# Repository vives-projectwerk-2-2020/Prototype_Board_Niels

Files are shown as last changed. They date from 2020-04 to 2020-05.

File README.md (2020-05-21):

# Prototype board with sensors

## Description

In this readme you can find all information about the prototype board with sensors. I made first a test board this board cannot be placed inside the box. This board works perfect with all sensors. The second board i made is made to put inside the box, i also implemented extra pins for the other boards. I also added a extra part to get the SDS011 sensor in sleep mode i will explain this in the info below.

## The nucleo

The central part of my board is the nucleo-L432KC. The STM32 Nucleo-32 board provides an affordable and flexible way for users to try out new concepts and build prototypes with the STM32 microcontroller, choosing from the various combinations of performance, power consumption and features. In the picture below you can see how the nucleo looks like and how the pins are devided. If i talk about pins in the info beneeth you can look on this picture where you can find the pins.

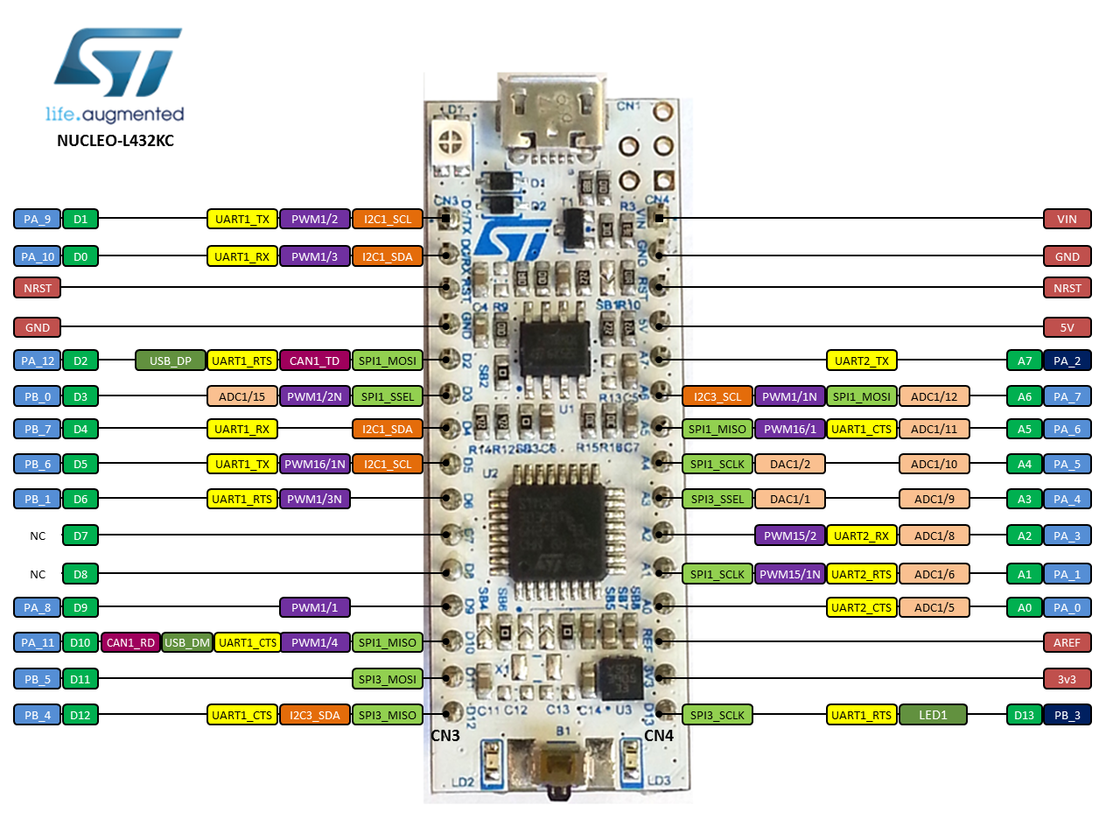
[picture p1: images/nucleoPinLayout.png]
nucleo pin layout


## Shematic of the old board

In this shematic you see in the center of the shematic 2 big blocks the top one is the left side of the nucleo-L432KC. The block below is the right side of the nucleo-L432KC. On the right side from the second nucleo-L432KC block you can see 2 pins they are called JP2 and JP3. These pins were provided for the solar panel board, JP2 is connected with the Vin from the nucleo and JP3 is just the ground. There is also a reset button connected to NRST on the nucleo.

Right below the pins JP2 and JP3 you can see one big connector, this is the connector for connecting the LoRaWAN-antenna board. Pins 1, 8, 9 are connected to the ground, pin 12 is connected with the 3V3 and a capacitor with a value of 100 nF.
Pins 7, 10, 11, 15 are not connected, pin 2 is connected to pin D12 on the nucleo. Pin 3 is connected with D11 on the nucleo, pin 4 is connected with D13 on the nucleo, pin 5 is connected with D0 on the nucleo. Pin 6 is connected with a resistor with a value of 4k7 ohm, this pin is also connected with D1 on the nucleo. Pin 13 is connected with D2 on the nucleo, pin 14 is connected with D3 on the nucleo.

Left from the top block from the nulceo you can see a connector that is called SDS011. This connector has pins so that you connect the SDS011 sensor on it. You can see that pin 1 is not connected this is because the connector from the SDS011 has 5 pins and one is not connected. Pin 2 is connected to 3v3 but this has been changed in the newer shematic because the sensor has to work on 5V, pin 3 is connected to the ground. Pin 4 is connected to D1 on the nucleo and Pin 5 is connected to D0 on the nucleo.

Right from the top block from the nulceo you can see a connector that is called BME280. This connector has female pins so you can put the BME280 sensor on it. Pin 2 is not connected, Pin 1 and 7 are connected to 3V3 and pin 3 and 5 are connected to the ground. Pin 4 is connected to D5 on the nucleo and pin 6 is connected to D4 on the nucleo.

On top of the shematic you can see a big block this is the EEPROM. Pin 2 is connected to the ground and pin 4 is connected to the VCC. Pin 5 is not connected, pin 1 is connected to a resistor with a value of 2k2 ohm to protect the SCL line and is connected tot the D5 on the nucleo. Pin 3 is connected to a resistor with a value of 2k2 ohm to protect the SDA line and is connected with D4 on the nucleo.

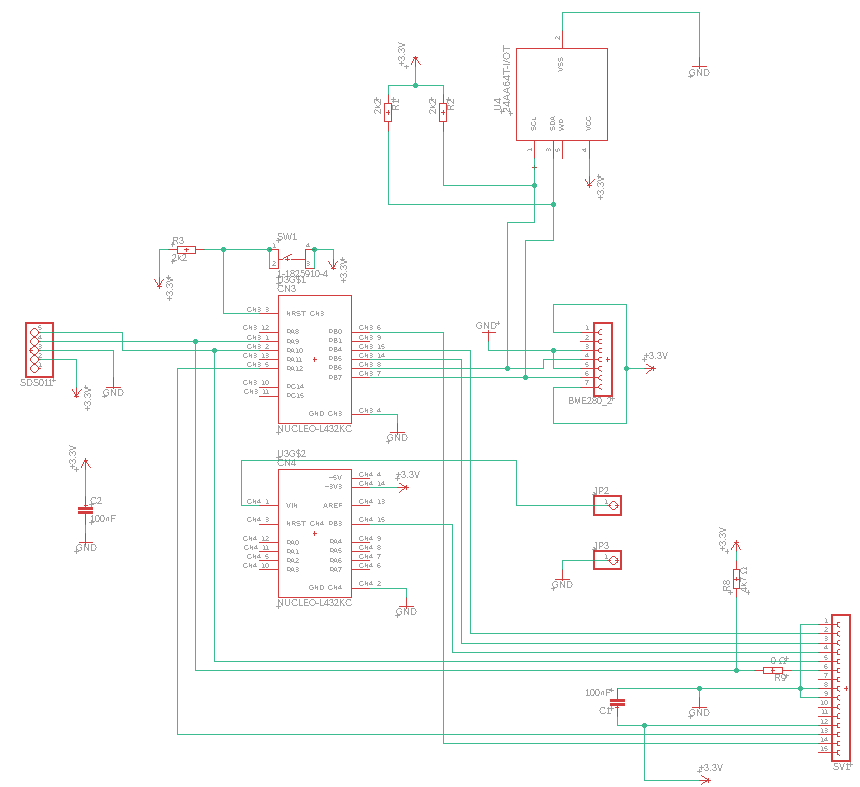
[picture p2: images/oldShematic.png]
old shematic


## Block diagram old board

Here can you see the block diagram of the old board. This block diagram is a quick summary of what is on my old board.

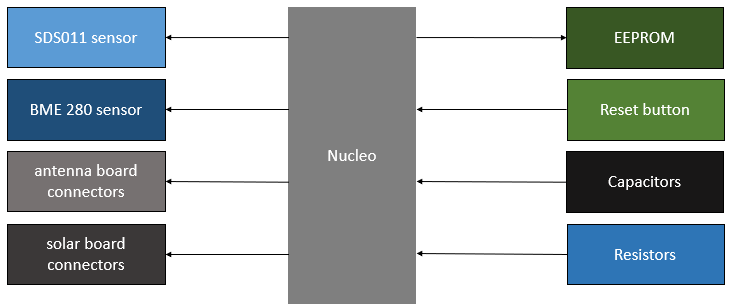
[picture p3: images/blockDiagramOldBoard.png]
old block diagram


## Board shematic of the old board

On the top of the board you can see 4 holes this is the VCC of the SDS011 sensor. These holes are were provided so you could erase the line and add more voltage to it from the solar pannel board. These holes were removed on the newest board.

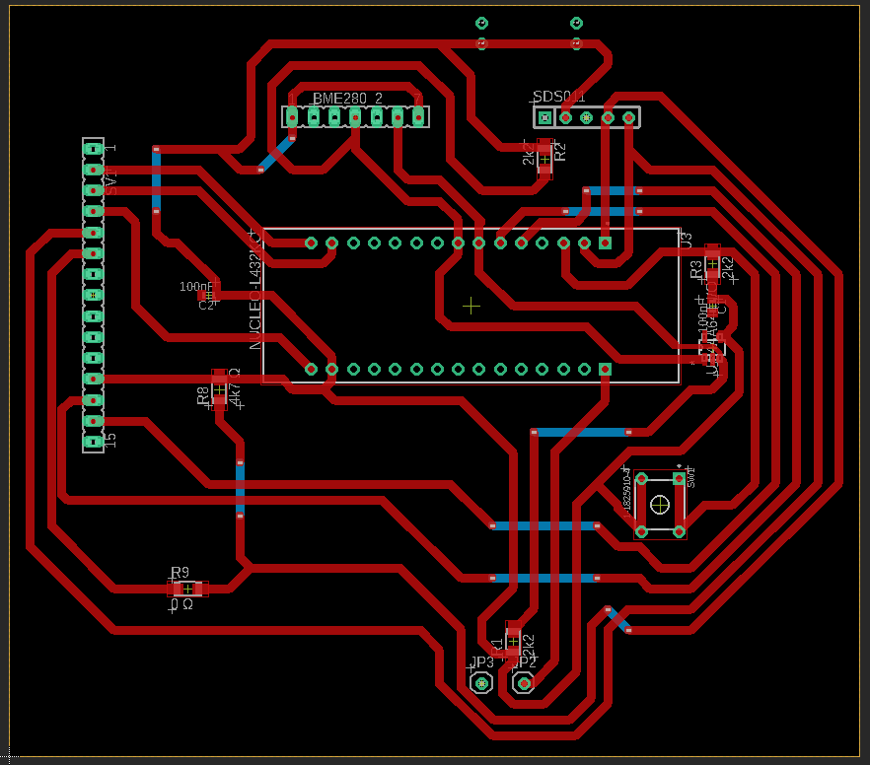
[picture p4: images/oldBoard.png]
old board


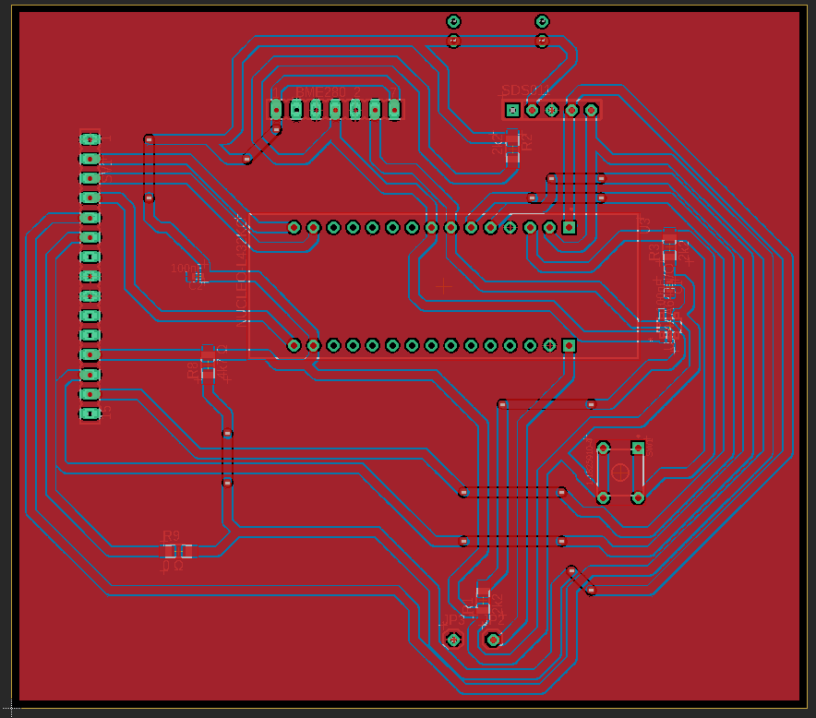
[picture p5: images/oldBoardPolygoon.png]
old board polygoon


## The print when nothing was soldered

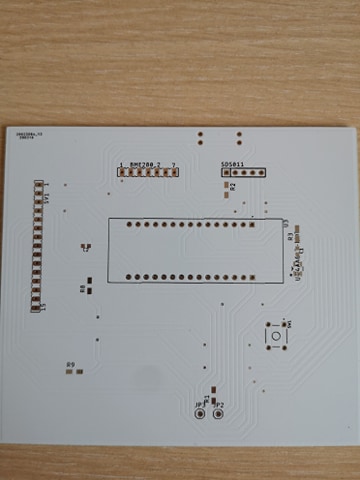
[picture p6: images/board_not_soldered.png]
print not soldered


## The print when everything is soldered

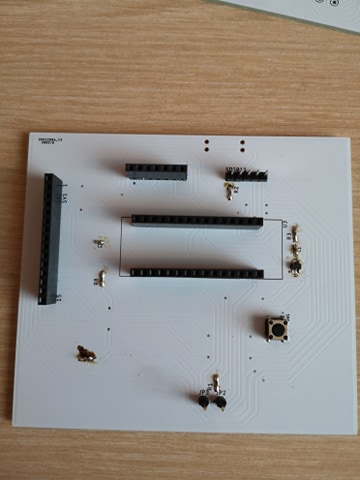
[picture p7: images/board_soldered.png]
print soldered


## Testing the SDS011 sensor

1. Setup of the sensor.

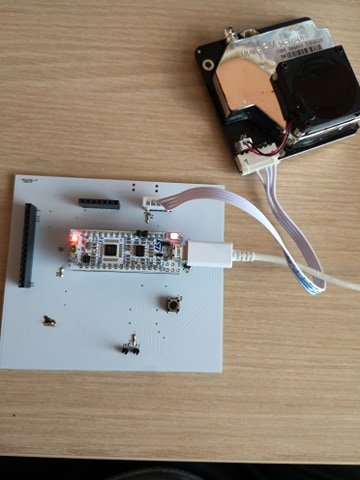
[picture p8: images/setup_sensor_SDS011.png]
setup SDS011
   

2. Reading the values in putty.

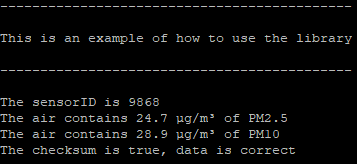
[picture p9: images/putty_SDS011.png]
putty SDS011
   

3. Extra information.
    * The pins are connected on D0 and D1.

## Testing the EEPROM driver

1. Setup of the sensor.

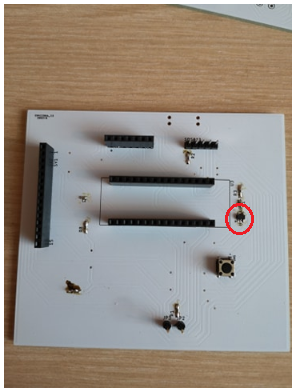
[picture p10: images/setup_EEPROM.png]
setup EEPROM
   

2. Reading out an array in putty.

   putty EEPROM

3. Extra information.
    * While testing i connected the pins to D4 and D5.

## Testing the BME280 sensor

I could not test this sensor because i don't have that sensor at home. I tested it with the fake values from Ladzlo and something was wrong with compiling. But other people tried this sensor and connected it just like how i connected it in my shematic so normally it would work perfectly.

1. Setup of the sensor.

   Connect the sensor in the pins in the red circle shown in the picture below.

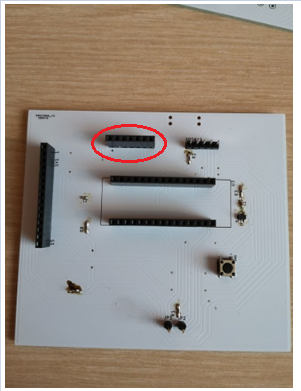
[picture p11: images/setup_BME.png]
setup BME
   

2. Extra information.
    * I connected the BME to pins D4 and D5 on the nucleo.

## Testing antenna PCB board

This test has been executed by Laura this pcb works perfectly together with my board all the info about the tests can you find in the github repository from the antenna board.

1. Setup of the boards.

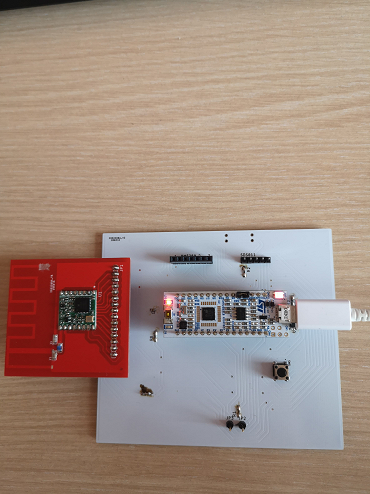
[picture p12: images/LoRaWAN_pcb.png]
setup LoRaWan
   

2. Extra information.
    * You can find extra information in the link below.
    * [Link testing LoRaWAN-antenna](https://github.com/vives-projectwerk-2-2020/LoRaWAN-antenna)

## Shematic of the new board

The difference between the old and the new board is that i added extra pins for the battery pcb and also pins for an extra board so that the voltage can go from 3V3 to 5V so that the SDS011 sensor can work well. I also added sleep mode for the SDS011.

Left from the lowest nucleo shematic i added added 3 extra connectors. SV3 is provided so that the solar board can be connected to my board. SV2 are connectors to add the extra print that converts te voltage 3V3 to 5V, we have to do that so that the SDS011 can function well.

Below the SV2 connector there are 2 pins these pins are provided to connect the wires from the batteries to my pcb. In the board you can also see a lot of holes. These holes are provided to connect the pcb with the box, the 2 holes in the center are provided for the batteries you can connect these under the PCB or above.

In the top left of the shematic you can see i added there also extra components. These components are provided so that the SDS011 can go in sleep mode. I connected this to pin D2 on the nucleo, the info about the shematic can you find in the topic "Adding components to the old board so that the SDS011 sensor can go in sleep mode" this will be discussed below.

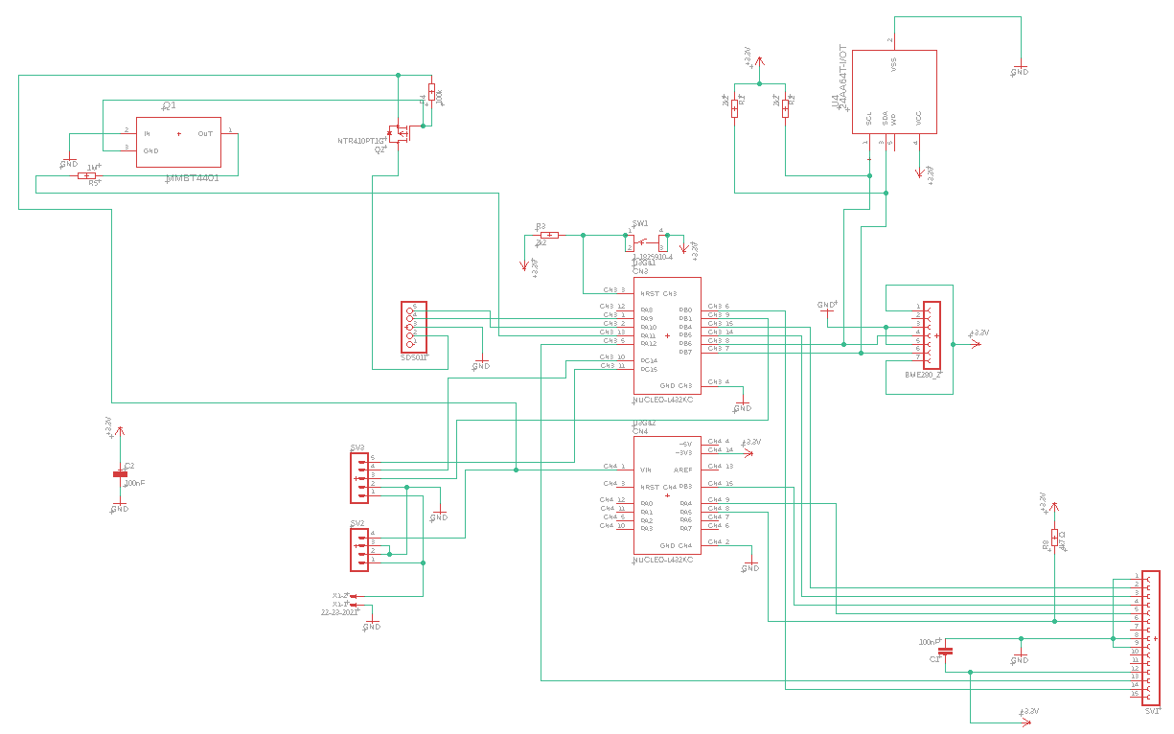
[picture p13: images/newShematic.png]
shematic of new board


## Adding components to the old board so that the SDS011 sensor can go in sleep mode

I upgraded the old shematic a bit so that the SDS011 sensor can go in sleep mode. In the picture below you can see the shematic about how to make it.

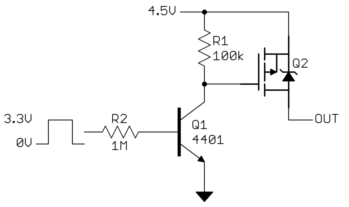
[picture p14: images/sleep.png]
shematic of sleepmode


When the digital output goes high, Q1 is turned on. That pulls down the gate of Q2 low, turning it on.
When the digital output is low, Q1 is held off. R1 then pulls the gate high, turning off Q2.
R1 was chosen to be so high to minimize the current when the device is powered on.

## Block diagram new board

Here can you see the block diagram of the new board. This block diagram is a quick summary of what is on my new board.

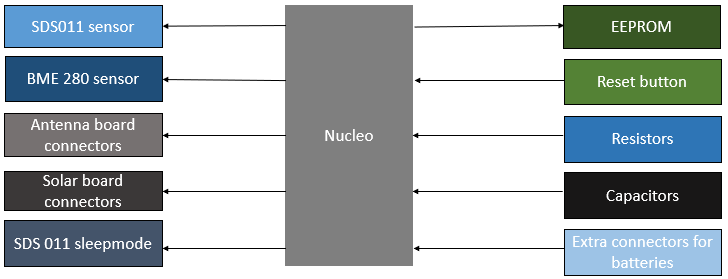
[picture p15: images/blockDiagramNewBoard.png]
old block diagram


## Board shematic of the new board

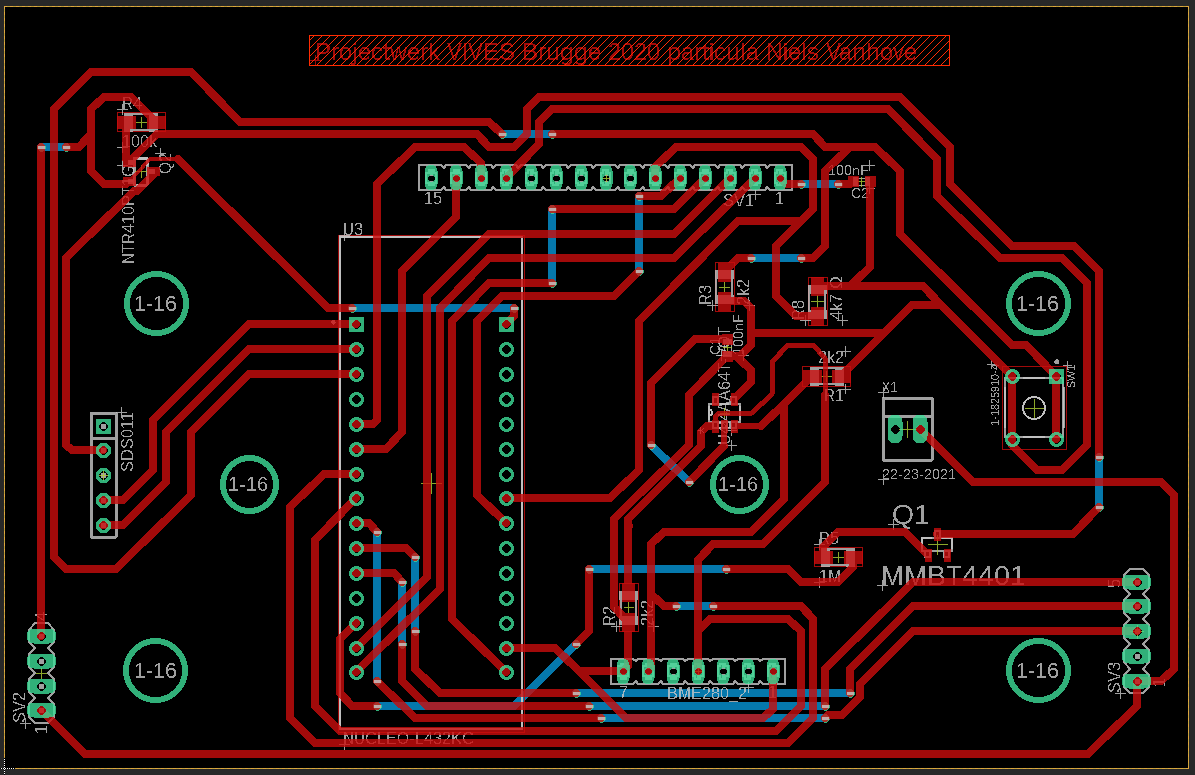
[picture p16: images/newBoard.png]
new board


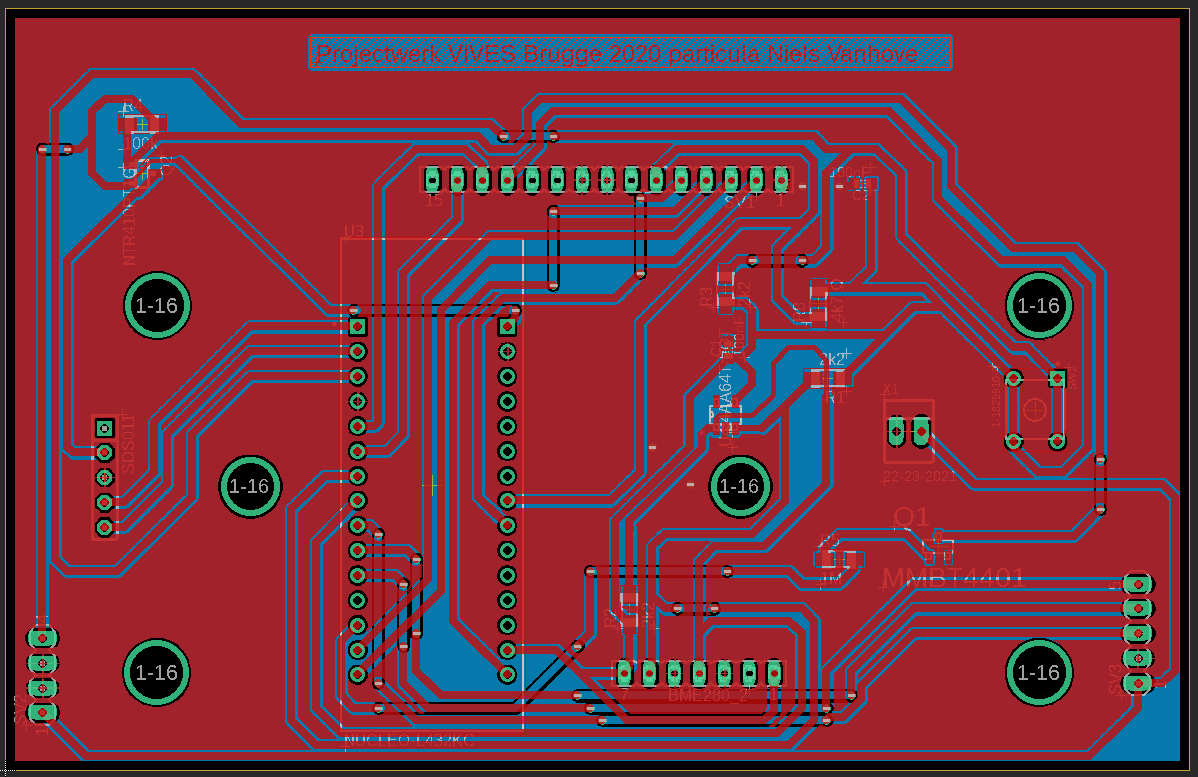
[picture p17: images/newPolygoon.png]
new polygoon


## The waterproof box

All the boards from the hardware needs to be combined in this waterproof box. In the picture below you can see how we arranged the prints in the box. The grey sensor board is my board, all the other boards will be connected to my board with connectors or with holes in the pcb. I can connect also my pcb to the box. You can see in the picture that the antenna board is far away from the other pcb's. This is because the antenna may not get malfunctions from other boards. The part that is not on the picture but in the box are the batteries. You can add the batteries under my print or add it on top of it with spacers.

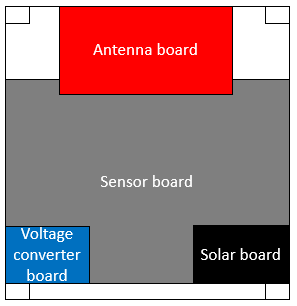
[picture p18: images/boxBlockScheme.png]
block scheme box
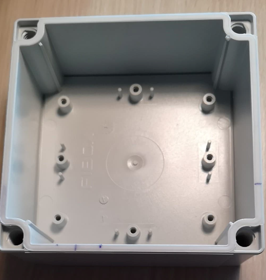
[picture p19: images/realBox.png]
real box
 

## Partlist

* [Female header](https://be.farnell.com/samtec/ssw-107-01-t-s/connector-rcpt-7pos-1row-2-54mm/dp/2667434)
* [Pinheader SDS011](https://be.farnell.com/molex/22-28-4050/connector-header-5pos-1row-2-54mm/dp/2381173)
* [Push button](https://be.farnell.com/c-k-components/pts645sl43-2-lfs/tactile-switch-spst-0-05a-12vdc/dp/2435161)
* [EEPROM](https://be.farnell.com/microchip/24aa64t-i-ot/serial-eeprom-64kbit-400khz-sot/dp/2101260)
* [100 nF capacitor](https://be.farnell.com/avx/02016d104kat2a/cap-0-1-f-6-3v-10-x5r-0201/dp/1657913?st=smd%20capacitor)
* [2k2 ohm resistor](https://be.farnell.com/vishay/crcw06032k20fkeahp/res-2k2-1-0-33w-0603-thick-film/dp/1738909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)
* [100k ohm resistor](https://be.farnell.com/vishay/crcw0402100kfked/res-100k-1-0-063w-0402-thick-film/dp/1469671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)
* [1M ohm resistor](https://be.farnell.com/vishay/crcw04021m00fked/res-1m-1-0-063w-0402-thick-film/dp/1469667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)
* [4k7 ohm resistor](https://be.farnell.com/vishay/crcw06034k70fkea/res-4k7-1-0-1w-0603-thick-film/dp/1469807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)
* [15 pins Female header](https://be.farnell.com/harwin/m20-7821546/connector-rcpt-15pos-2-54mm-1row/dp/3225931)
* [4 pins Female header](https://be.farnell.com/multicomp/2212s-04sg-85/socket-pcb-1-row-4way/dp/1593460)
* [5 pins Female header](https://be.farnell.com/multicomp/2212s-05sg-85/socket-pcb-1-row-5way/dp/1593461)
* [2 pins Male header](https://be.farnell.com/amp-te-connectivity/5-146281-2/board-board-connector-header-2/dp/1792060)
* [Nucleo](https://be.farnell.com/stmicroelectronics/nucleo-l432kc/dev-board-nucleo-32/dp/2580786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)
* [Transistor](https://be.farnell.com/on-semiconductor/mmbt4401lt1g/transistor-npn-sot-23/dp/1459105?st=MMBT4401)
* [Mosfet](https://be.farnell.com/on-semiconductor/ntr4101pt1g/mosfet-p-20v-sot-23/dp/1431303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)

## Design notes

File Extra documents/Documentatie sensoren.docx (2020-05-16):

Bosh BME280 TPH sensor

1. I²C Wiring
- Connect Vin to the power supply, 3-5V is fine. Use the same voltage that the microcontroller logic is based off of. For most Arduinos, that is 5V
- Connect GND to common power/data ground
- Connect the SCK pin to the I2C clock SCL pin on your Arduino. On an UNO & '328 based Arduino, this is also known as A5, on a Mega it is also known as digital 21 and on a Leonardo/Micro, digital 3
- Connect the SDI pin to the I2C data SDA pin on your Arduino. On an UNO & '328 based Arduino, this is also known as A4, on a Mega it is also known as digital 20 and on a Leonardo/Micro, digital 2

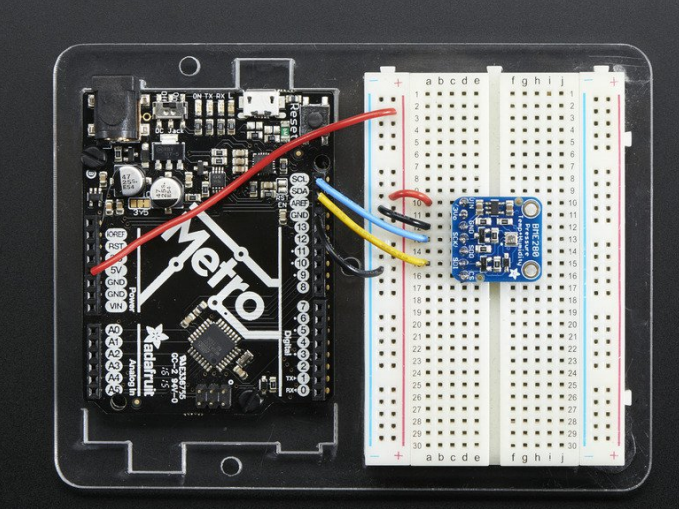
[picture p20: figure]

2. SPI Wiring
- Connect Vin to the power supply, 3V or 5V is fine. Use the same voltage that the microcontroller logic is based off of. For most Arduinos, that is 5V
- Connect GND to common power/data ground
- Connect the SCK pin to Digital #13 but any pin can be used later
- Connect the SDO pin to Digital #12 but any pin can be used later
- Connect the SDI pin to Digital #11 but any pin can be used later
- Connect the CS pin Digital #10 but any pin can be used later

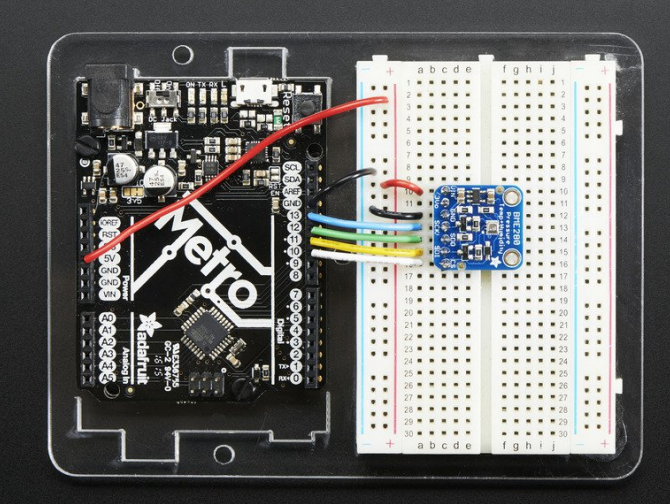
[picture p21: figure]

Particle sensor: SDSO11

- Deze sensor gebruikt UART
- Power requirement:
  - Power Voltage：4.7~5.3V
  - Power supply：>1W
  - Supply voltage ripple：<20mV
- Interface specifications

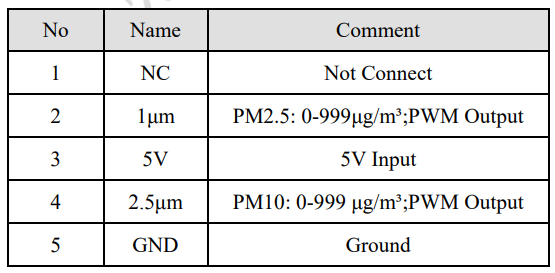
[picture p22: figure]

- The UART communication protocol
  - Bit rate ：9600
  - Data bit ：8
  - Parity bit：NO
  - Stop bit ：1
  - Data Packet frequency: 1Hz

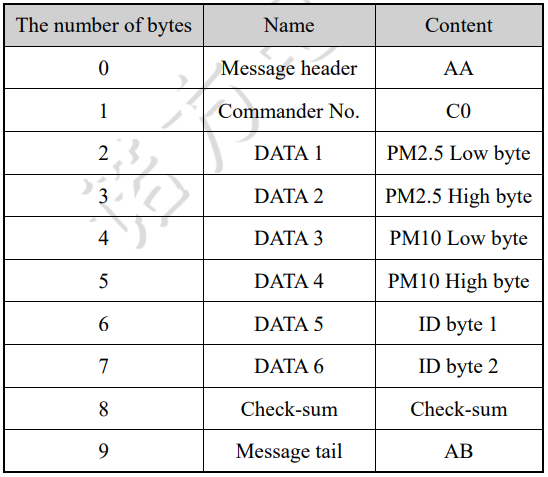
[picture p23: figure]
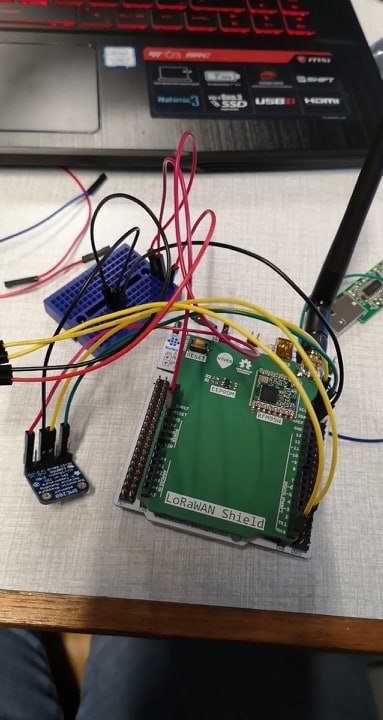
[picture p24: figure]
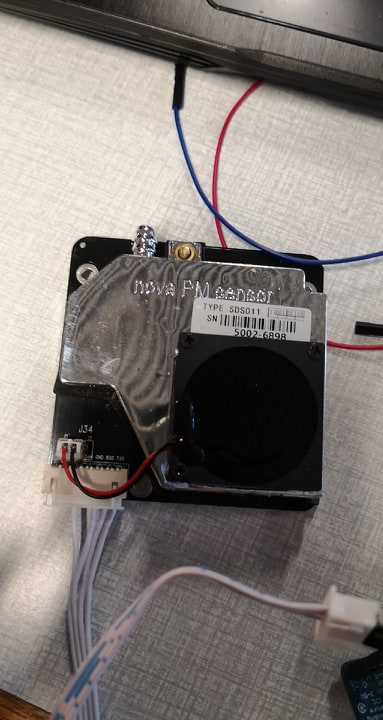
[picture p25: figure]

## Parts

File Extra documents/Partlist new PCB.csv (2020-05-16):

Part | Value | Device | Package | Description | Links
BME280_2 |  | FE07-1 | FE07 | FEMALE HEADER | https://be.farnell.com/samtec/ssw-107-01-t-s/connector-rcpt-7pos-1row-2-54mm/dp/2667434
C1 | 100nF | C-EUC0603K | C0603K | CAPACITOR, European symbol | https://be.farnell.com/avx/02016d104kat2a/cap-0-1-f-6-3v-10-x5r-0201/dp/1657913?st=smd%20capacitor
C2 | 100nF | C-EUC0603K | C0603K | CAPACITOR, European symbol | https://be.farnell.com/avx/02016d104kat2a/cap-0-1-f-6-3v-10-x5r-0201/dp/1657913?st=smd%20capacitor
Q1 | MMBT4401 | LM3480IM3-5.0 | SOT95P263X110-3N | Linear Voltage Regulator | https://be.farnell.com/on-semiconductor/mmbt4401lt1g/transistor-npn-sot-23/dp/1459105?st=MMBT4401
Q2 | NTR410PT1G | BSS84LT1 | SOT23 | OnSemi's BSS84LT1 Power MOSFET 130 mA, 50 V RDS(on) = 10 | https://be.farnell.com/on-semiconductor/ntr4101pt1g/mosfet-p-20v-sot-23/dp/1431303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
R1 | 2k2 | R-EU_R1206W | R1206W | RESISTOR, European symbol | https://be.farnell.com/vishay/crcw06032k20fkeahp/res-2k2-1-0-33w-0603-thick-film/dp/1738909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
R2 | 2k2 | R-EU_R1206W | R1206W | RESISTOR, European symbol | https://be.farnell.com/vishay/crcw06032k20fkeahp/res-2k2-1-0-33w-0603-thick-film/dp/1738909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
R3 | 2k2 | R-EU_R1206W | R1206W | RESISTOR, European symbol | https://be.farnell.com/vishay/crcw06032k20fkeahp/res-2k2-1-0-33w-0603-thick-film/dp/1738909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
R4 | 100k | R-EU_R1206W | R1206W | RESISTOR, European symbol | https://be.farnell.com/vishay/crcw0402100kfked/res-100k-1-0-063w-0402-thick-film/dp/1469671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
R5 | 1M | R-EU_R1206W | R1206W | RESISTOR, European symbol | https://be.farnell.com/vishay/crcw04021m00fked/res-1m-1-0-063w-0402-thick-film/dp/1469667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
R8 | 4k7 Ω | R-EU_R1206W | R1206W | RESISTOR, European symbol | https://be.farnell.com/vishay/crcw06034k70fkea/res-4k7-1-0-1w-0603-thick-film/dp/1469807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
SDS011 |  | PINHD-1X5 | 1X05 | PIN HEADER | https://be.farnell.com/molex/22-28-4050/connector-header-5pos-1row-2-54mm/dp/2381173
SV1 |  | FE15-1 | FE15 | FEMALE HEADER | https://be.farnell.com/harwin/m20-7821546/connector-rcpt-15pos-2-54mm-1row/dp/3225931
SV2 |  | MA04-1 | MA04-1 | PIN HEADER | https://be.farnell.com/multicomp/2212s-04sg-85/socket-pcb-1-row-4way/dp/1593460
SV3 |  | MA05-1 | MA05-1 | PIN HEADER | https://be.farnell.com/multicomp/2212s-05sg-85/socket-pcb-1-row-5way/dp/1593461
SW1 | 1-1825910-4 | 1-1825910-4 | TE_1-1825910-4 | Switch Tactile OFF (ON) | https://be.farnell.com/c-k-components/pts645sl43-2-lfs/tactile-switch-spst-0-05a-12vdc/dp/2435161
U3 | NUCLEO-L432KC | NUCLEO-L432KC | MODULE_NUCLEO-L432KC | STM32 Nucleo-32 development board | https://be.farnell.com/microchip/24aa64t-i-ot/serial-eeprom-64kbit-400khz-sot/dp/2101260
U4 | 24AA64T-I/OT | 24AA64T-I/OT | SOT-23-5_MC |  | https://be.farnell.com/stmicroelectronics/nucleo-l432kc/dev-board-nucleo-32/dp/2580786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
X1 | 22-23-2021 | 22-23-2021 | 22-23-2021 | .100 (2.54mm) Center Header - 2 Pin" | https://be.farnell.com/amp-te-connectivity/5-146281-2/board-board-connector-header-2/dp/1792060

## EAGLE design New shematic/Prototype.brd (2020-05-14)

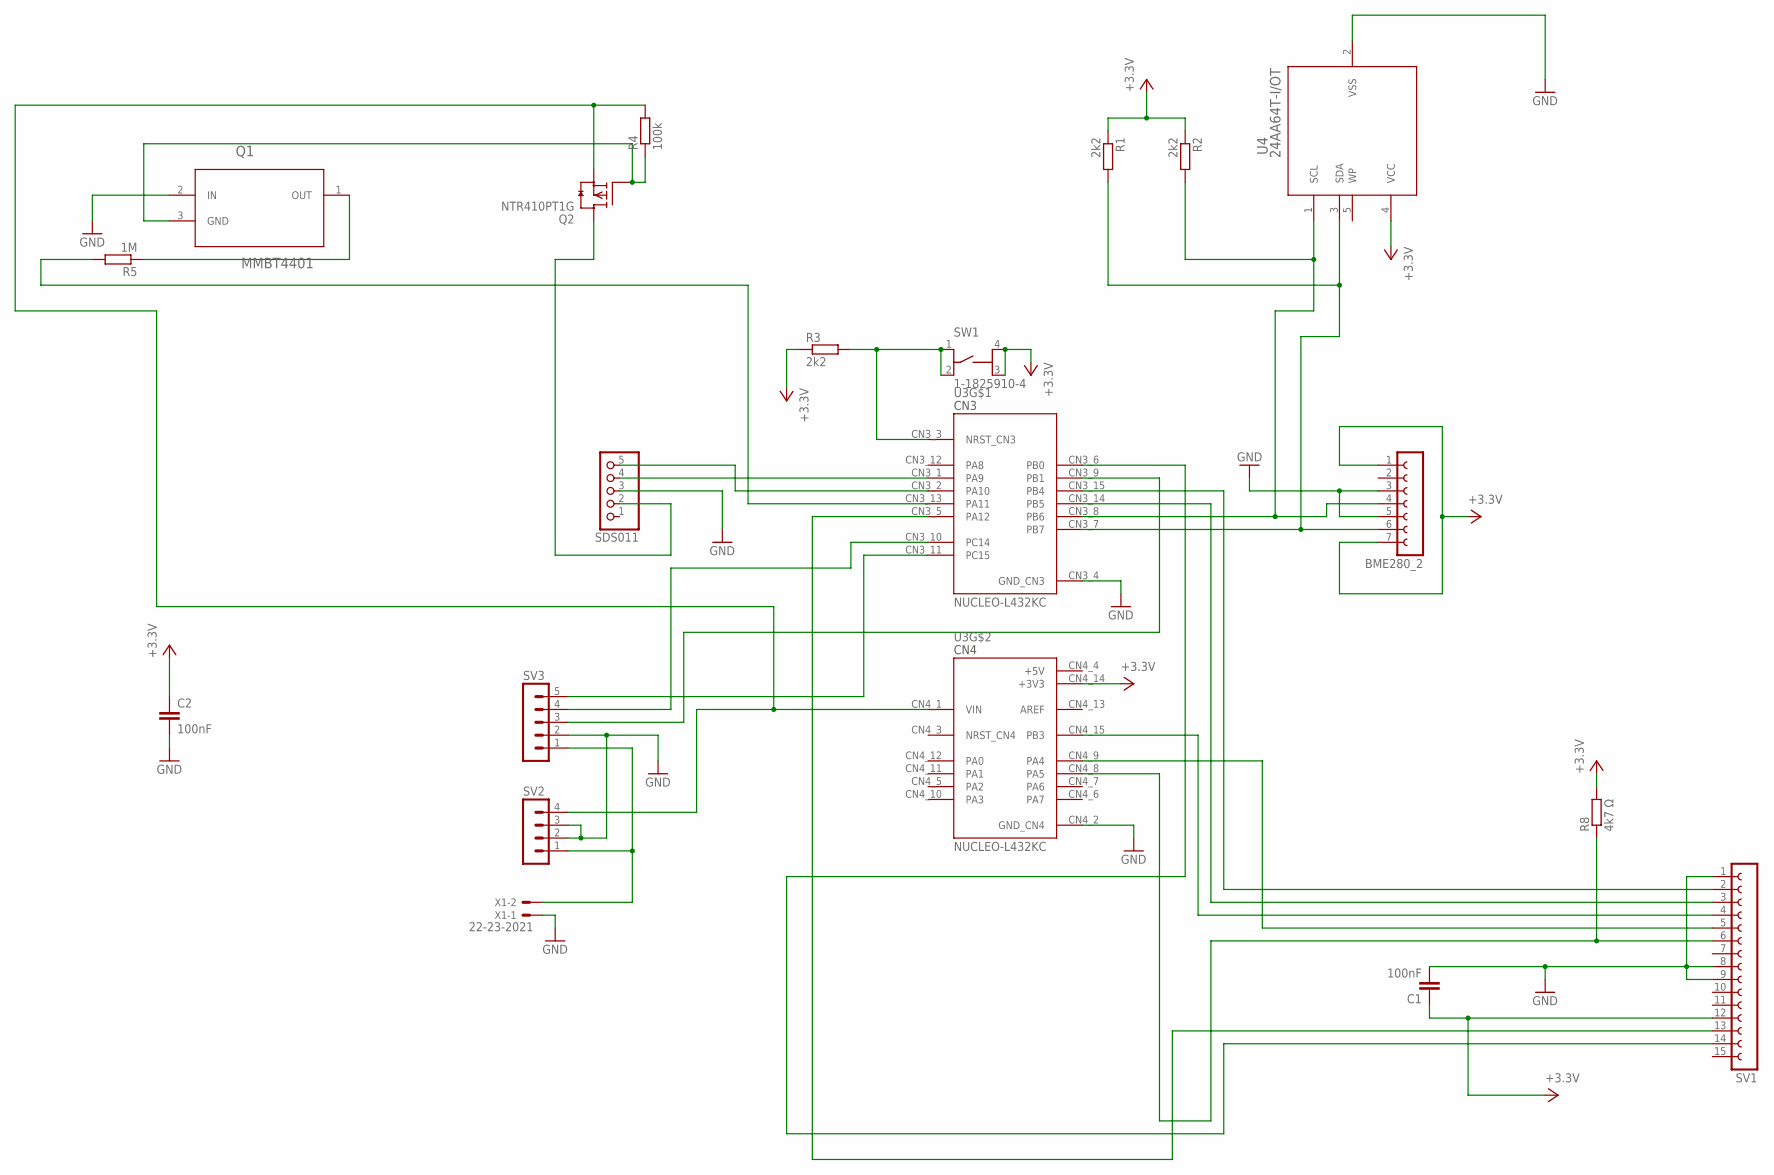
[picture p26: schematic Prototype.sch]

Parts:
BME280_2: FE07-1; FE07
C1, C2: 100nF; C0603K
Q1: MMBT4401; SOT95P263X110-3N
Q2: NTR410PT1G; SOT23
R1, R2, R3: 2k2; R1206W
R4: 100k; R1206W
R5: 1M; R1206W
R8: 4k7 Ω; R1206W
SDS011: PINHD-1X5; 1X05
SV1: FE15-1; FE15
SV2: MA04-1
SV3: MA05-1
SW1: 1-1825910-4; TE_1-1825910-4
U3: NUCLEO-L432KC; MODULE_NUCLEO-L432KC
U4: 24AA64T-I/OT; SOT-23-5_MC
X1: 22-23-2021

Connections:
+5V: U3.CN4_4 (+5V)
GND: BME280_2.3, BME280_2.5, C1.2, C2.2, Q1.2 (IN), SDS011.3, SV1.1, SV1.8, SV1.9, SV2.2, SV2.3, SV3.2, U3.CN3_4 (GND_CN3), U3.CN4_2 (GND_CN4), U4.2 (VSS), X1.1
unnamed: SV1.5, U3.CN4_9 (PA4)
unnamed: SDS011.4, U3.CN3_1 (PA9)
unnamed: SV1.14, U3.CN3_6 (PB0)
unnamed: BME280_2.4, R2.2, U3.CN3_8 (PB6), U4.1 (SCL)
unnamed: R3.2, SW1.1, SW1.2, U3.CN3_3 (NRST_CN3)
unnamed: SDS011.5, U3.CN3_2 (PA10)
unnamed: Q1.3 (GND), Q2.1 (G), R4.1
unnamed: Q2.3 (D), SDS011.2
unnamed: SV1.13, U3.CN3_5 (PA12)
unnamed: R8.1, SV1.6, U3.CN4_8 (PA5)
unnamed: SV1.3, U3.CN3_14 (PB5)
unnamed: Q2.2 (S), R4.2, SV2.4, U3.CN4_1 (VIN)
unnamed: SV1.2, U3.CN3_15 (PB4)
unnamed: SV1.4, U3.CN4_15 (PB3)
unnamed: Q1.1 (OUT), R5.1
unnamed: SV2.1, SV3.1, X1.2
unnamed: BME280_2.6, R1.2, U3.CN3_7 (PB7), U4.3 (SDA)
unnamed: SV3.3, U3.CN3_9 (PB1)
unnamed: SV3.4, U3.CN3_10 (PC14)
unnamed: SV3.5, U3.CN3_11 (PC15)
unnamed: R5.2, U3.CN3_13 (PA11)
VCC: BME280_2.1, BME280_2.7, C1.1, C2.1, R1.1, R2.1, R3.1, R8.2, SV1.12, SW1.3, SW1.4, U3.CN4_14 (+3V3), U4.4 (VCC)

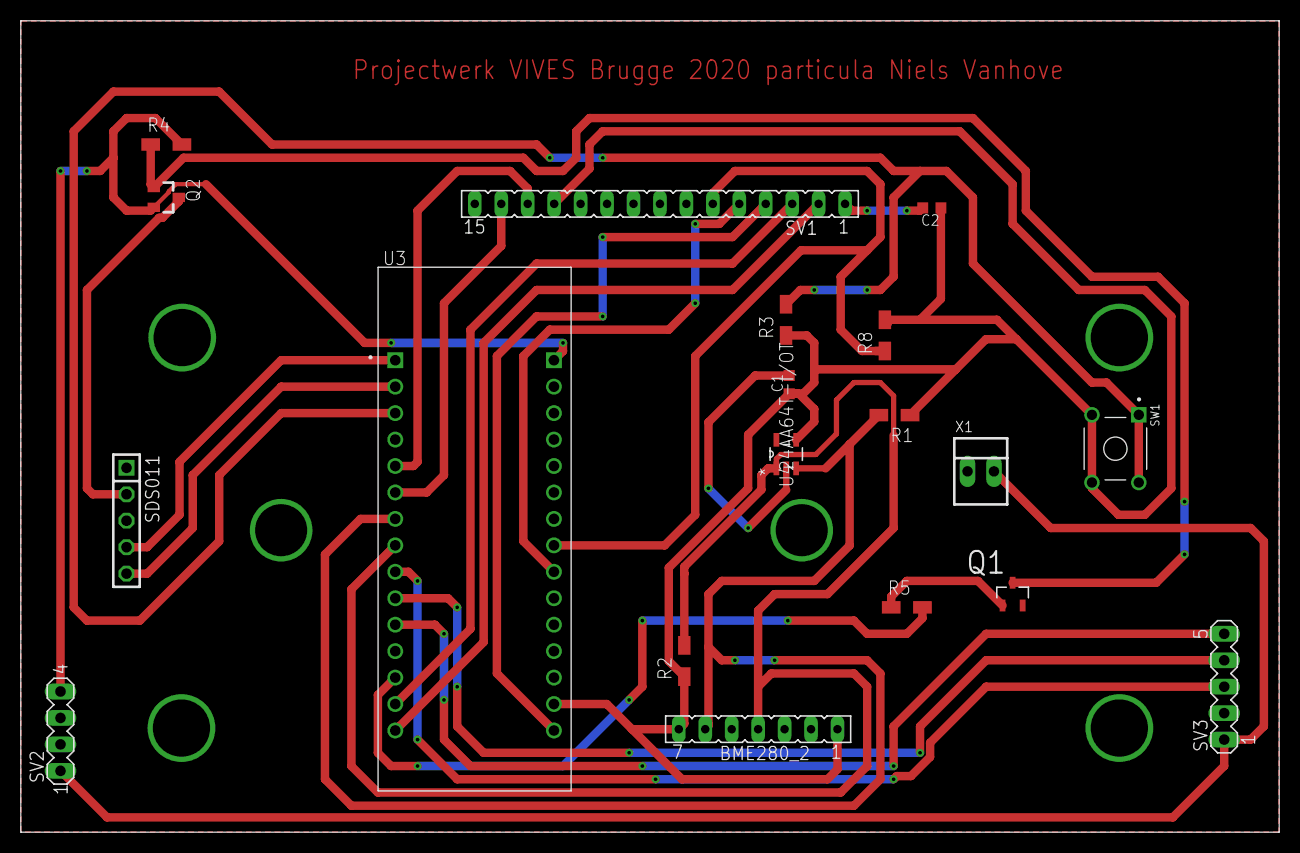
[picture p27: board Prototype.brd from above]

Board: 2 copper layers, 120.8 x 77.9 mm, 19 parts (0 on the bottom side), 23 nets.

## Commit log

2020-04-07 added the shematic to github but this is already in an other github repository
    [Prototype.brd, Prototype.sch]
2020-04-07 added 2 pictures of the board
2020-04-15 tested the EEPROM driver and it worked + added some documentation about the settup and the result in putty
2020-05-08 made new board and shematic
    [Prototype.brd, Prototype.sch]
2020-05-12 remaked the pcb board
    [Prototype.brd, Prototype.sch]
2020-05-14 refactored the shematic and added components so that sensor can go in sleep
    [Prototype.brd, Prototype.sch]
2020-05-16 added old shematic and description to readme
    [Prototype.sch]
2020-05-16 added board shematic to the readme
2020-05-16 added some extra info to the boards
2020-05-16 added info about the BME sensor
2020-05-16 added info about the lora wan board
2020-05-16 added new board to readme
2020-05-16 adding extra documents + updating shematic
    [Prototype.sch]
2020-05-16 added part list to readme
    [Partlist new PCB.csv, Partlist old PCB.csv]
2020-05-16 changed link to antenna project

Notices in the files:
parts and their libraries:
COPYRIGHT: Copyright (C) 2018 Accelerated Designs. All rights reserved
